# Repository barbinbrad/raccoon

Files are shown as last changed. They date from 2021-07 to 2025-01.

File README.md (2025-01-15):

# Raccoon
PCB and firmware for a USB to CAN interface, with support for 4 CAN transceivers and an optional NEO-MP8 GNSS module. The design is a reverse-engineering of comma.ai's Black Panda. It uses a modified version of the [panda](https://github.com/commaai/panda) firmware/SDK.

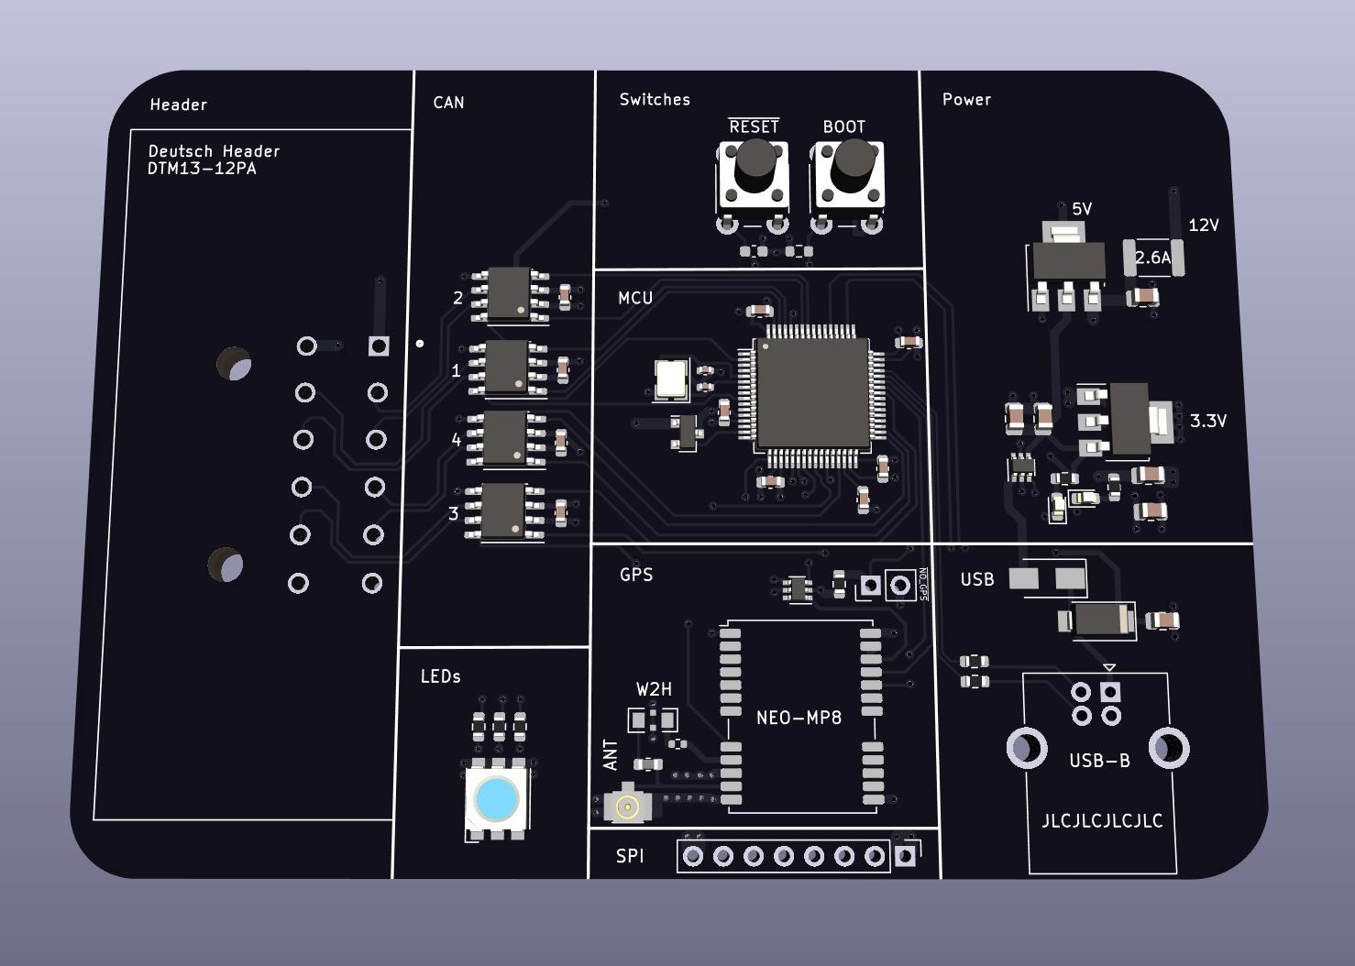
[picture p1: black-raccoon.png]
board


## Usage
For self-driving, it is better to buy a [red panda](https://comma.ai/shop/products/panda) from comma.ai. In addition to getting a more reliable product, you'll be supporting open-source software and a really smart group of people.

## Header

The design uses an automotive-grade Deutsch header, which eliminates the need for a switching relay. Feel free to replace this with something else. If you want to use ["ODB-C"](https://github.com/commaai/neo/blob/master/car_harness/OBD-C.sch.pdf) you'll need to use pins C0/C3 (inputs), C10/C11 (outputs). 

To use the deutsch header, you'll need a [crimper](https://www.buydeutsch.com/collections/crimpers/products/18890) and some parts:

- 1 [DTM13-12A](https://www.alliedelec.com/product/te-connectivity/dtm13-12pa/70979342/) or some variant of the header. This needs hand-soldered.
- 1 [DTM06-12S](https://www.buydeutsch.com/collections/dtm-series/products/dtm06-12sa), the male connector
- 1 [WM-12S](https://www.buydeutsch.com/collections/dtm-series/products/wm-12s), a wedgelock
- 12 [Crimpable Sockets](https://www.buydeutsch.com/products/0462-201-20141)

## Hand-Soldered Components
There are a few components that need purchased and hand-soldered to make the board work.
- 1 [USB-B Connector](https://www.digikey.com/en/products/detail/molex,-llc/0670688000/773801)
- 2 [Push Button Switches](https://www.mouser.com/ProductDetail/Grayhill/95C06C3RAT)

## GPS
If you order the board as-is from JLCPCB, you can use it with or without GPS. 

To use it with GPS, you'll need to hand-solder/install these parts:

- 1 [NEO-MP8-2](https://www.digikey.com/en/products/detail/u-blox/NEO-M8P-2/6150645)
- 1 [W2H15C4738AT1A](https://www.digikey.com/en/products/detail/avx-corporation/W2H15C4738AT1A/2004490), a feedthrough capacitor for the GPS antenna. 
- 1 Active GNSS Antenna. See [Table 7](https://www.u-blox.com/sites/default/files/NEO-8Q-NEO-M8-FW3_HIM_UBX-15029985.pdf) in the NEO-M8P guide for recommendations. 

To use it without GPS, just jump the through-holes labeled NO_GPS. This will tell the firmware to ignore the GPS.

## Warning
The board design is untested because of the chip shortage. Use at your own risk.

## Credit
Credit to [mickabrig7](https://github.com/mickabrig7/raccoon) for the original design and his guidance.

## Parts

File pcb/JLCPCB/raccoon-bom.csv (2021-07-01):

Comment | Designator | Footprint | LCSC
10p | C10,C12 | Capacitor_SMD:C_0402_1005Metric | C32949
100n | C11,C14,C15,C16,C17,C18,C19,C20,C21,C22 | Capacitor_SMD:C_0603_1608Metric | C14663
4.7u | C13 | Capacitor_SMD:C_0603_1608Metric | C19666
10u | C3,C4,C5,C6,C8,C9 | Capacitor_SMD:C_0805_2012Metric | C15850
D_Schottky | D1,D5 | Diode_SMD:D_SMA | C8678
LED_RGB | D2 | LED_SMD:LED_RGB_5050-6 | C409780
GREEN | D3 | LED_SMD:LED_0603_1608Metric | C72043
RED | D4 | LED_SMD:LED_0603_1608Metric | C2286
2.6A | F1 | Fuse:Fuse_1812_4532Metric | C207183
W2H | FL1 | raccoon:W2H15C4738AT1A
USB_B | J1 | Connector_USB:USB_B_OST_USB-B1HSxx_Horizontal
U.FL-R-SMT(01) | J2 | kicad-footprints:HRS_U.FL-R-SMT(01) | C88373
DTM13-12PA | J3 | kicad-footprints:TE_DTM13-12PA
Conn_01x08_Female | J4 | Connector_PinHeader_2.54mm:PinHeader_1x08_P2.54mm_Vertical
Conn_01x02_Female | J5 | Connector_PinHeader_2.54mm:PinHeader_1x02_P2.54mm_Vertical
27 nH | L1 | Inductor_SMD:L_0603_1608Metric | C12100
Q_NMOS_GSD | Q1 | Package_TO_SOT_SMD:SOT-23 | C8545
22 | R1,R2 | Resistor_SMD:R_0603_1608Metric | C23345
10 | R10 | Resistor_SMD:R_0402_1005Metric | C25077
10k | R3,R4 | Resistor_SMD:R_0603_1608Metric | C25804
100 | R5,R6,R7 | Resistor_SMD:R_0603_1608Metric | C22775
820 | R8 | Resistor_SMD:R_0603_1608Metric | C23253
4.7k | R9 | Resistor_SMD:R_0603_1608Metric | C23162
SW_SPST | SW1,SW2 | Button_Switch_THT:SW_PUSH_6mm_H8mm
SiP32431DR3 | U1,U2 | Package_TO_SOT_SMD:SOT-363_SC-70-6 | C141606
NEO-M8P | U11 | RF_GPS:ublox_NEO
AMS1117-5.0 | U3 | Package_TO_SOT_SMD:SOT-223-3_TabPin2 | C6187
AMS1117-3.3 | U4 | Package_TO_SOT_SMD:SOT-223-3_TabPin2 | C6186
STM32F413RGT6 | U6 | Package_QFP:LQFP-64_10x10mm_P0.5mm | C468260
TJA1042T-3 | U7,U8,U9,U10 | Package_SO:SOIC-8_3.9x4.9mm_P1.27mm | C132227
16MHz | Y1 | Crystal:Crystal_SMD_3225-4Pin_3.2x2.5mm | C13738

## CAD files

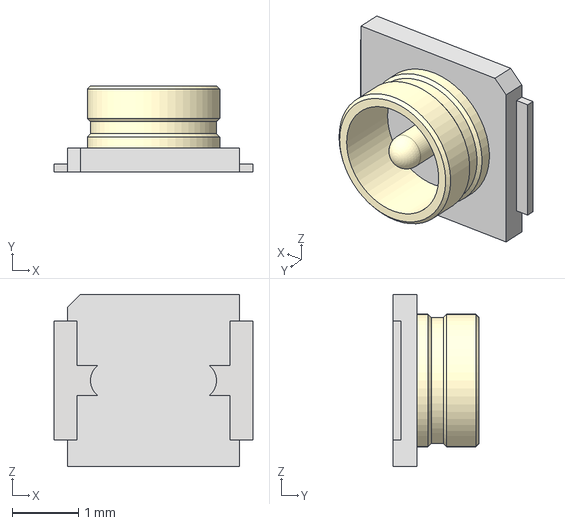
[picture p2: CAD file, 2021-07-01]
pcb/raccoon.3d/U.FL Connector.stp
3.00 x 1.30 x 2.60 mm

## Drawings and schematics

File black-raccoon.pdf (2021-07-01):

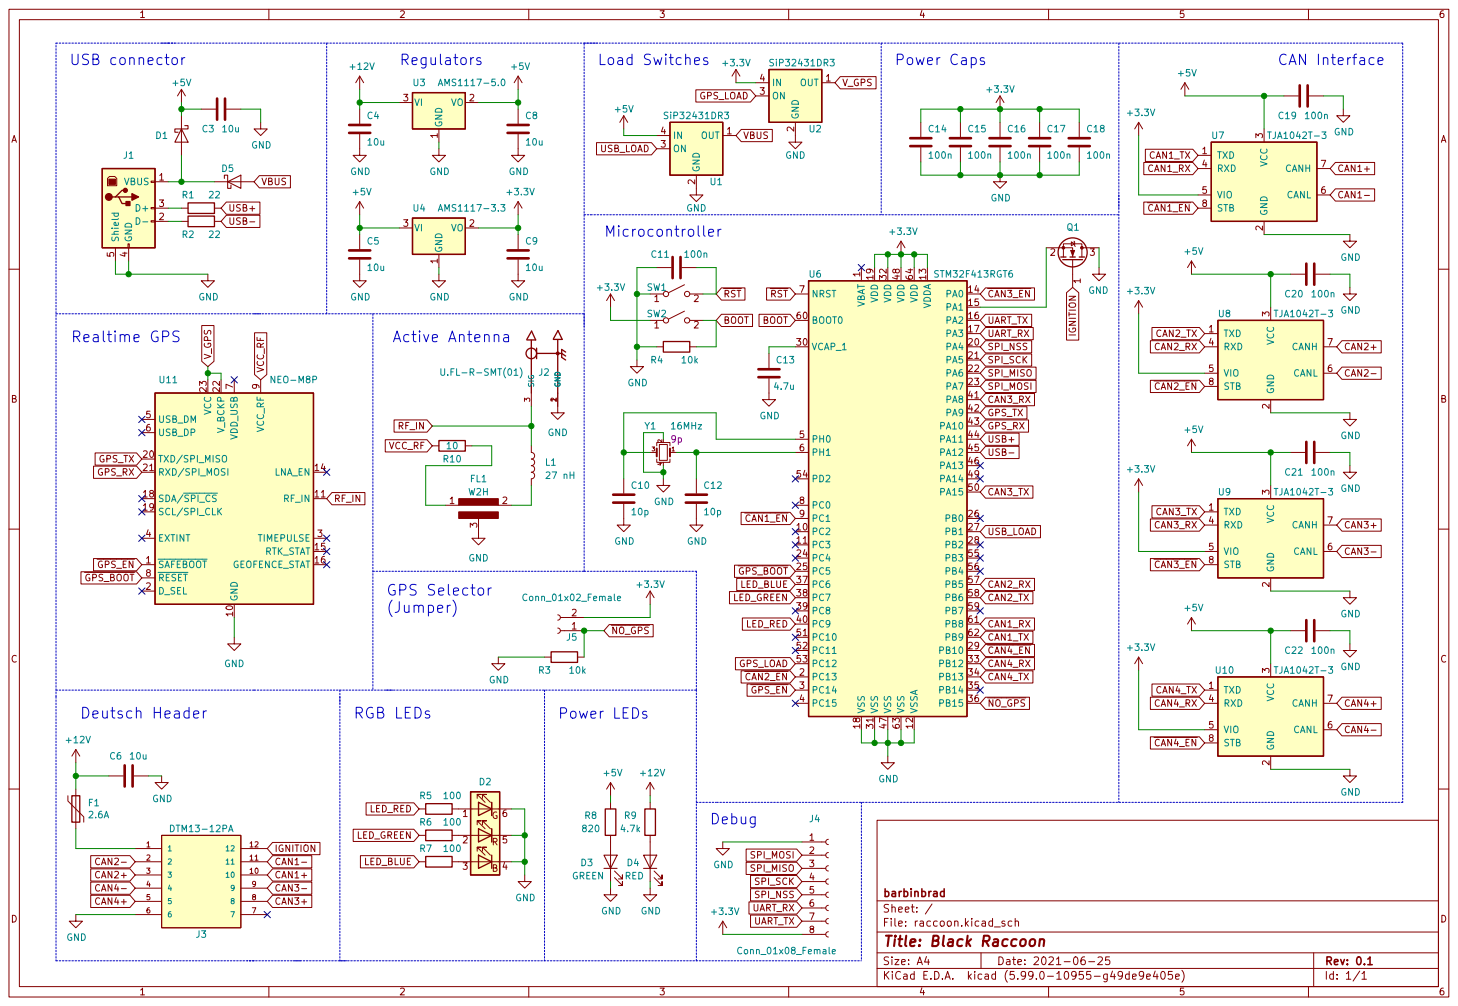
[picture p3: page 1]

1 VO 2 VI 3 U3 AMS1117-5.0 GND GND GND

3 RXD 4 VIO 5 CANL 6 CANH 7 STB 8 U8 TJA1042T-3 +5V

1 PC2 10 PC3 11 VSSA 12 VDDA 13 PA0 14 PA1 15 PA2 16 PA3 17 VSS 18 VDD 19 PC13 2 PA4 20 PA5 21 PA6 22 PA7 23 PC4 24 PC5 25 PB0 26 PB1 27 PB2 28 PB10 29 PC14 3 VCAP_1 30 VSS 31 VDD 32 PB12 33 PB13 34 PB14 35 PB15 36 PC6 37 PC7 38 PC8 39 PC15 4 PC9 40 PA8 41 PA9 42 PA10 43 PA11 44 PA12 45 PA13 46 VSS 47 VDD 48 PA14 49 PH0 5 PA15 50 PC10 51 PC11 52 PC12 53 PD2 54 PB3 55 PB4 56 PB5 57 PB6 58 PB7 59 PH1 6 BOOT0 60 PB8 61 PB9 62 VSS 63 VDD 64 NRST 7 PC0 8 PC1 9 U6 STM32F413RGT6 C3 10u OUT 1 GND

3 RXD 4 VIO 5 CANL 6 CANH 7 STB 8 U7 TJA1042T-3 C20 100n GND

3 U.FL-R-SMT(01) J2 GND GND GND

3 RXD 4 VIO 5 CANL 6 CANH 7 STB 8 U9 TJA1042T-3 GND

3 RXD 4 VIO 5 CANL 6 CANH 7 STB 8 U10 TJA1042T-3 GND

File: raccoon.kicad_sch Sheet: / barbinbrad

Id: 1/1 Title: Black Raccoon

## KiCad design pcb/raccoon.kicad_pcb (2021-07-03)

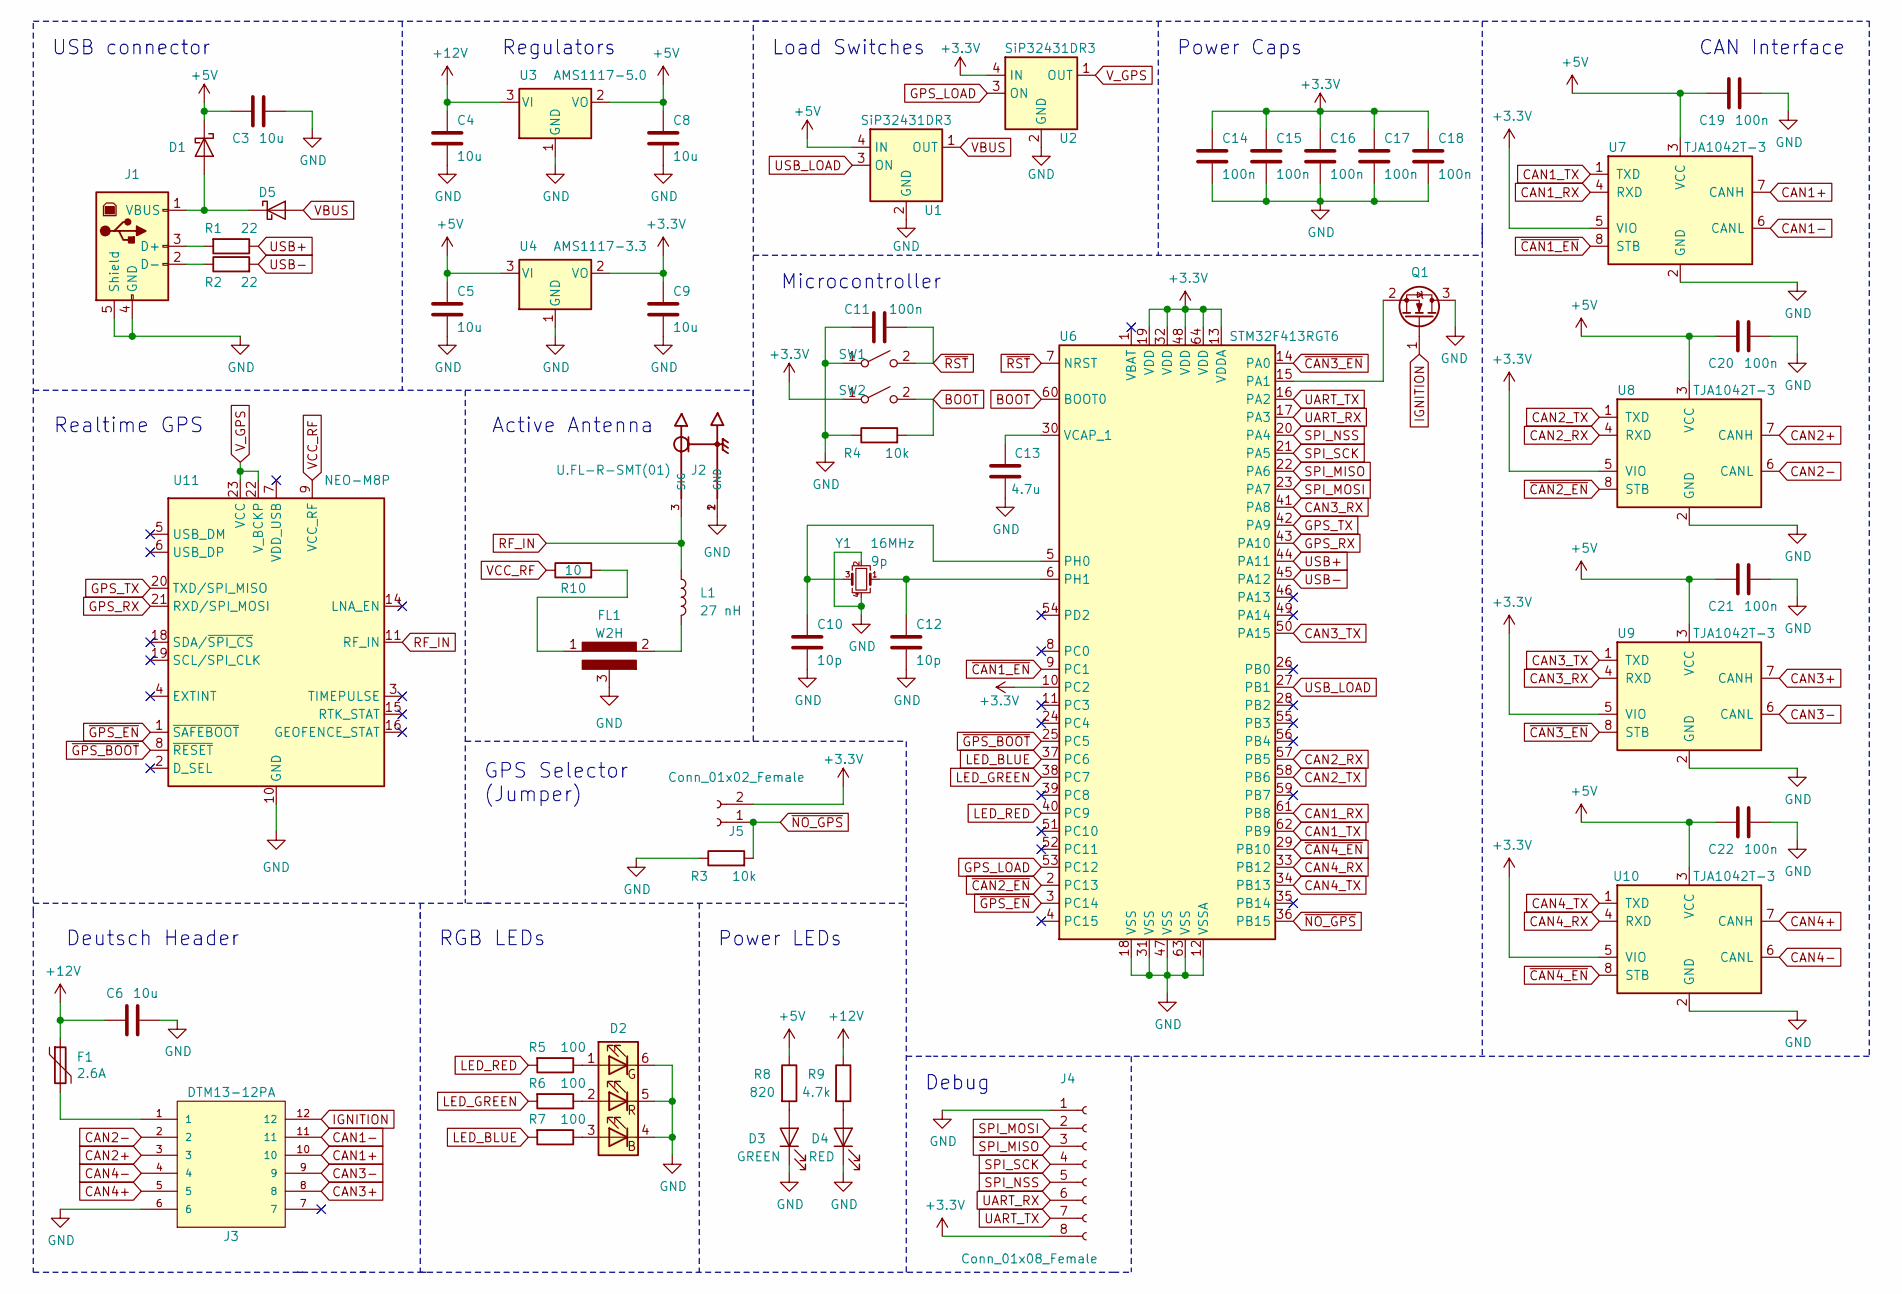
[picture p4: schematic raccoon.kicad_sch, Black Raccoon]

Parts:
C3, C4, C5, C6, C8, C9: 10u; C_0805_2012Metric; LCSC C15850
C10, C12: 10p; C_0402_1005Metric; LCSC C32949
C11, C14, C15, C16, C17, C18, C19, C20, C21, C22: 100n; C_0603_1608Metric; LCSC C14663
C13: 4.7u; C_0603_1608Metric; LCSC C19666
D1, D5: D_Schottky; D_SMA; LCSC C8678
D2: LED_RGB; LED_RGB_5050-6; LCSC C409780
D3: GREEN; LED_0603_1608Metric; LCSC C72043
D4: RED; LED_0603_1608Metric; LCSC C2286
F1: 2.6A; Fuse_1812_4532Metric; LCSC C207183
FL1: W2H; W2H15C4738AT1A
J1: USB_B; USB_B_OST_USB-B1HSxx_Horizontal
J2: U.FL-R-SMT(01); HRS_U.FL-R-SMT(01); LCSC C88373
J3: DTM13-12PA; TE_DTM13-12PA
J4: Conn_01x08_Female; PinHeader_1x08_P2.54mm_Vertical
J5: Conn_01x02_Female; PinHeader_1x02_P2.54mm_Vertical
L1: 27 nH; L_0603_1608Metric; LCSC C12100
Q1: Q_NMOS_GSD; SOT-23; LCSC C8545
R1, R2: 22; R_0603_1608Metric; LCSC C23345
R3, R4: 10k; R_0603_1608Metric; LCSC C25804
R5, R6, R7: 100; R_0603_1608Metric; LCSC C22775
R8: 820; R_0603_1608Metric; LCSC C23253
R9: 4.7k; R_0603_1608Metric; LCSC C23162
R10: 10; R_0402_1005Metric; LCSC C25077
SW1, SW2: SW_SPST; SW_PUSH_6mm_H8mm
U1, U2: SiP32431DR3; SOT-363_SC-70-6; LCSC C141606
U3: AMS1117-5.0; SOT-223-3_TabPin2; LCSC C6187
U4: AMS1117-3.3; SOT-223-3_TabPin2; LCSC C6186
U6: STM32F413RGT6; LQFP-64_10x10mm_P0.5mm; LCSC C468260
U7, U8, U9, U10: TJA1042T-3; SOIC-8_3.9x4.9mm_P1.27mm; LCSC C132227
U11: NEO-M8P; ublox_NEO
Y1: 16MHz; Crystal_SMD_3225-4Pin_3.2x2.5mm; LCSC C13738

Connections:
+3V3: C9.1, C14.1, C15.1, C16.1, C17.1, C18.1, J4.8, J5.2, SW2.1 (A), U2.4 (IN), U4.2 (VO), U6.10 (PC2), U6.13 (VDDA), U6.19 (VDD), U6.32 (VDD), U6.48 (VDD), U6.64 (VDD), U7.5 (VIO), U8.5 (VIO), U9.5 (VIO), U10.5 (VIO)
+5V: C3.2, C5.1, C8.1, C19.2, C20.2, C21.2, C22.2, D1.1 (K), R8.1, U1.4 (IN), U3.2 (VO), U4.3 (VI), U7.3 (VCC), U8.3 (VCC), U9.3 (VCC), U10.3 (VCC)
+12V: C4.1, C6.2, F1.1, R9.1, U3.3 (VI)
BOOT: R4.2, SW2.2 (B), U6.60 (BOOT0)
CAN1+: J3.10, U7.7 (CANH)
CAN1-: J3.11, U7.6 (CANL)
CAN1_RX: U6.61 (PB8), U7.4 (RXD)
CAN1_TX: U6.62 (PB9), U7.1 (TXD)
CAN2+: J3.3, U8.7 (CANH)
CAN2-: J3.2, U8.6 (CANL)
CAN2_RX: U6.57 (PB5), U8.4 (RXD)
CAN2_TX: U6.58 (PB6), U8.1 (TXD)
CAN3+: J3.8, U9.7 (CANH)
CAN3-: J3.9, U9.6 (CANL)
CAN3_RX: U6.41 (PA8), U9.4 (RXD)
CAN3_TX: U6.50 (PA15), U9.1 (TXD)
CAN4+: J3.5, U10.7 (CANH)
CAN4-: J3.4, U10.6 (CANL)
CAN4_RX: U6.33 (PB12), U10.4 (RXD)
CAN4_TX: U6.34 (PB13), U10.1 (TXD)
GND: C3.1, C4.2, C5.2, C6.1, C8.2, C9.2, C10.2, C11.2, C12.2, C13.1, C14.2, C15.2, C16.2, C17.2, C18.2, C19.1, C20.1, C21.1, C22.1, D2.4 (BK), D2.5 (GK), D2.6 (RK), D3.1 (K), D4.1 (K), FL1.3, J1.4 (GND), J1.5 (Shield), J2.1 (GND), J2.2 (GND), J3.6, J4.1, Q1.3 (D), R3.1, R4.1, SW1.1 (A), U1.2 (GND), U1.5 (GND), U2.2 (GND), U2.5 (GND), U3.1 (GND), U4.1 (GND), U6.12 (VSSA), U6.18 (VSS), U6.31 (VSS), U6.47 (VSS), U6.63 (VSS), U7.2 (GND), U8.2 (GND), U9.2 (GND), U10.2 (GND), U11.10 (GND), U11.12 (GND), U11.13 (GND), U11.24 (GND), Y1.2, Y1.4
GPS_LOAD: U2.3 (ON), U6.53 (PC12)
GPS_RX: U6.43 (PA10), U11.21 (RXD/SPI_MOSI)
GPS_TX: U6.42 (PA9), U11.20 (TXD/SPI_MISO)
IGNITION: J3.12, Q1.1 (G)
LED_BLUE: R7.2, U6.37 (PC6)
LED_GREEN: R6.2, U6.38 (PC7)
LED_RED: R5.2, U6.40 (PC9)
unnamed: C10.1, U6.5 (PH0), Y1.3
unnamed: C12.1, U6.6 (PH1), Y1.1
unnamed: C13.2, U6.30 (VCAP_1)
unnamed: D1.2 (A), D5.1 (K), J1.1 (VBUS)
unnamed: D2.1 (RA), R5.1
unnamed: D2.2 (GA), R6.1
unnamed: D2.3 (BA), R7.1
unnamed: D3.2 (A), R8.2
unnamed: D4.2 (A), R9.2
unnamed: F1.2, J3.1
unnamed: FL1.1, R10.2
unnamed: FL1.2, L1.2
unnamed: J1.2 (D-), R2.1
unnamed: J1.3 (D+), R1.2
unnamed: Q1.2 (S), U6.15 (PA1)
RF_IN: J2.3 (SIG), L1.1, U11.11 (RF_IN)
SPI_MISO: J4.3, U6.22 (PA6)
SPI_MOSI: J4.2, U6.23 (PA7)
SPI_NSS: J4.5, U6.20 (PA4)
SPI_SCK: J4.4, U6.21 (PA5)
UART_RX: J4.6, U6.17 (PA3)
UART_TX: J4.7, U6.16 (PA2)
USB+: R1.1, U6.44 (PA11)
USB-: R2.2, U6.45 (PA12)
USB_LOAD: U1.3 (ON), U6.27 (PB1)
VBUS: D5.2 (A), U1.1 (OUT)
VCC_RF: R10.1, U11.9 (VCC_RF)
V_GPS: U2.1 (OUT), U11.22 (V_BCKP), U11.23 (VCC)
~CAN1_EN~: U6.9 (PC1), U7.8 (STB)
~CAN2_EN~: U6.2 (PC13), U8.8 (STB)
~CAN3_EN~: U6.14 (PA0), U9.8 (STB)
~CAN4_EN~: U6.29 (PB10), U10.8 (STB)
~GPS_BOOT~: U6.25 (PC5), U11.8 (~RESET)
~GPS_EN~: U6.3 (PC14), U11.1 (~SAFEBOOT)
~NO_GPS~: J5.1, R3.2, U6.36 (PB15)
~RST~: C11.1, SW1.2 (B), U6.7 (NRST)

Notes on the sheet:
USB connector
Realtime GPS
Deutsch Header
GPS Selector (Jumper)
Regulators
RGB LEDs
Active Antenna
Power LEDs
Load Switches
Microcontroller
Debug
Power Caps
CAN Interface

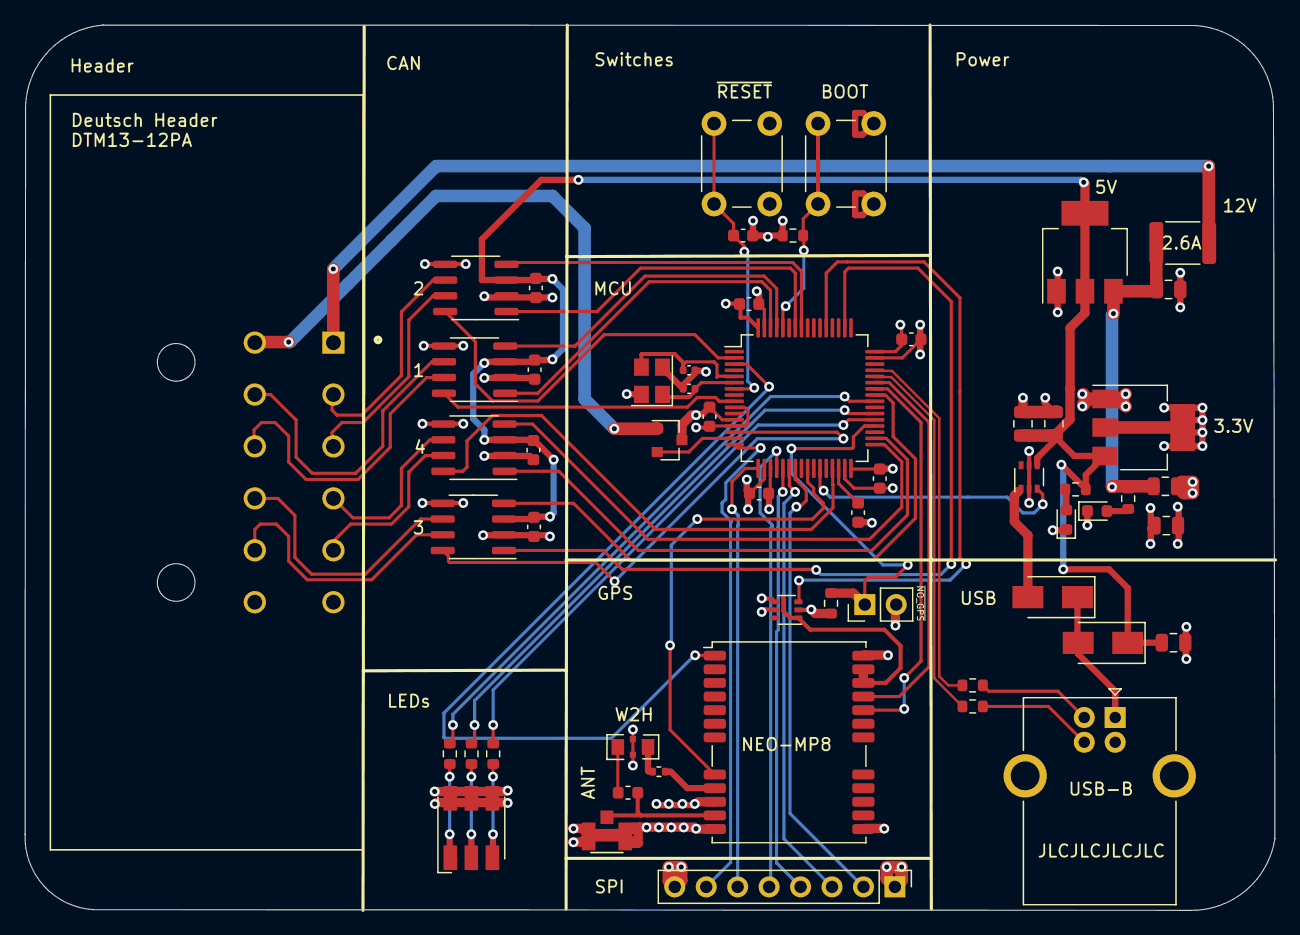
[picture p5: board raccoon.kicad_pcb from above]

Board: 4 copper layers, 100.9 x 71.5 mm, 56 parts (0 on the bottom side), 64 nets.

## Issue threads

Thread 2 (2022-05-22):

Some Faults?

lukasloetkolben, 2022-05-22:
I think I found two errors, but i am not sure.

I think in the Design the GPS_RX and GPS_TX is mixed up?
- RX (NEO-M8) should be connected to STM32s TX (PA10)
- TX (NEO-M8) should be connected to STM32s RX (PA9)

In Panda Code the RGB Pinsthe outputs are set to LOW to light up the LED.
I think in your design its reveresed?
`void black_set_led(uint8_t color, bool enabled) {
  switch (color){
    case LED_RED:
      set_gpio_output(GPIOC, 9, !enabled);
      break;
     case LED_GREEN:
      set_gpio_output(GPIOC, 7, !enabled);
      break;
    case LED_BLUE:
      set_gpio_output(GPIOC, 6, !enabled);`

lukasloetkolben, 2022-05-22:
USB+ and USB- on the Microcontroller are also mixed up.
On the GPS module GPS_EN is connected to SAFEBOOT and GPS_BOOT is connected to RESET, this should be wrong.

barbinbrad, 2022-05-22:
Great! Thanks a lot. Will you want to make an MR or would you prefer if I made the update?

lukasloetkolben, 2022-05-22:
would be nice if you can double check and update it yourself?
I am making my own BlackPanda :-)
